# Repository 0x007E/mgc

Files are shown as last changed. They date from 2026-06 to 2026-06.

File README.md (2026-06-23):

  

# `MGC` - MeGARCard

The `MGC` is built as base development board with a set of push-buttons, leds, potentiometers and many more components on-board. It builds the base platform for a bunchset of adaptable microcontrolles (e.g. `ATmega16A`, `ATmega4808`, `ESP32`). It simplifies the development process by extending supported microcontrollers to a range of actuators and sensors. The board itself regulates the voltage to `5V` or `3V3` automatically with a power mux ([TPS2116](#additional-information)). If `3V3` and `5V` are suppored, the voltage can be changed on the dip switch of the adaptable microcontroller board. The base board supports a usb or uart-interface [FT230XS](#additional-information) to the adaptable microcontroller. The usb mode can be switched over a usb-multiplexer [TS3USB30](#additional-information) within the dip switch on the base board. The leds on the base bord are controlled over a transistor array [TBD62783](#additional-information) that keeps the input current on a very low state. 

> Note that the board should be disconnected from power sources when changing the state of the dip switches on the base or microcontroller adapter board.

| Experience  | Level |
|:---|:---:|
| Soldering | ?% |
| Mechanical  | ?% |

# Adapter-Boards

| ATmega16A | ATmega4809 | ESP32 |
|:---:|:---:|:-----:|
| Bottom Layer | Bottom Layer | Bottom Layer |
| Schematic | Schematic | Schematic |
| [pdf](https://github.com/0x007E/mgc_m16a/releases/latest/download/schematic.pdf) / [cadlab](https://cadlab.io/project/30414/main/files) | [pdf](https://github.com/0x007E/mgc_m4809/releases/latest/download/schematic.pdf) / [cadlab](https://cadlab.io/project/30419/main/files) | [pdf](https://github.com/0x007E/mgc_esp32/releases/latest/download/schematic.pdf) / [cadlab](https://cadlab.io/project/30425/main/files) |
| [GitHub](https://github.com/0x007e/mgc_m16a) | [GitHub](https://github.com/0x007e/mgc_m4809) | [GitHub](https://github.com/0x007e/mgc_esp32) |

# Downloads

| Type | File | Description |
|:---:|:---:|:---|
| Schematic | [pdf](https://github.com/0x007E/mgc/releases/latest/download/schematic.pdf) / [cadlab](https://cadlab.io/project/30413/main/files) | Schematic files |
| Board | [pdf](https://github.com/0x007E/mgc/releases/latest/download/pcb.pdf) / [cadlab](https://cadlab.io/project/30413/main/files) | Board file |
| Drill | [pdf](https://github.com/0x007E/mgc/releases/latest/download/drill.pdf) | Drill file |
| BoM | [xlsx](https://github.com/0x007E/mgc/releases/latest/download/bom.xlsx) / [html](https://github.com/0x007E/mgc/releases/latest/download/ibom.html) | Bill of Material as Excel/interactive HTML |
| PCB | [zip](https://github.com/0x007E/mgc/releases/latest/download/kicad.zip) / [tar](https://github.com/0x007E/mgc/releases/latest/download/kicad.tar.gz) | KiCAD/Gerber/BoM/Drill files |
| Mechanical | [zip](https://github.com/0x007E/mgc/releases/latest/download/freecad.zip) / [tar](https://github.com/0x007E/mgc/releases/latest/download/freecad.tar.gz) | FreeCAD/Housing and PCB (STEP/STL) files |

# Hardware

The pcb is created with `KiCAD`, the housing with `FreeCAD`. All files are built with `github actions` so that they are ready for a production environment.

## PCB

The circuit board is populated on both sides (Top, Bottom). The best way for soldering the `SMD` components is within a vapor phase soldering system and for the `THT` components with a standard soldering system.

### Top Layer

Top Layer

### Bottom Layer

Bottom Layer

## Mechanical

The housing has a tolerance of `0.2mm` on each side of the case. So the pcb should fit perfectly in the housing. The tolerance can be modified with `FreeCAD` in the `Parameter` Spreadsheet.

### Assembled

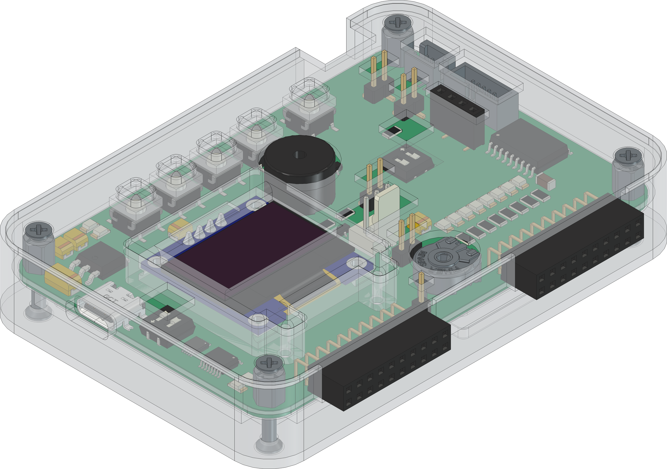
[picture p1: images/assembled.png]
Assembled


### Exploded

Exploded

# Additional Information

| Type | Link | Description |
|:---:|:---:|:---|
| FT230XS | [pdf](https://ftdichip.com/wp-content/uploads/2021/10/DS_FT230X.pdf) | USB/UART-Bridge |
| TS3USB30 | [pdf](https://www.ti.com/lit/ds/symlink/ts3usb30e.pdf) | USB-Multiplexer 1:2 |
| TPS2116 | [pdf](https://www.ti.com/lit/ds/symlink/tps2116.pdf) | Power Mux with Manual and Priority Switchover |
| TBD62783 | [pdf](https://toshiba.semicon-storage.com/info/datasheet_en_20160511.pdf) | DMOS transistor array |

---

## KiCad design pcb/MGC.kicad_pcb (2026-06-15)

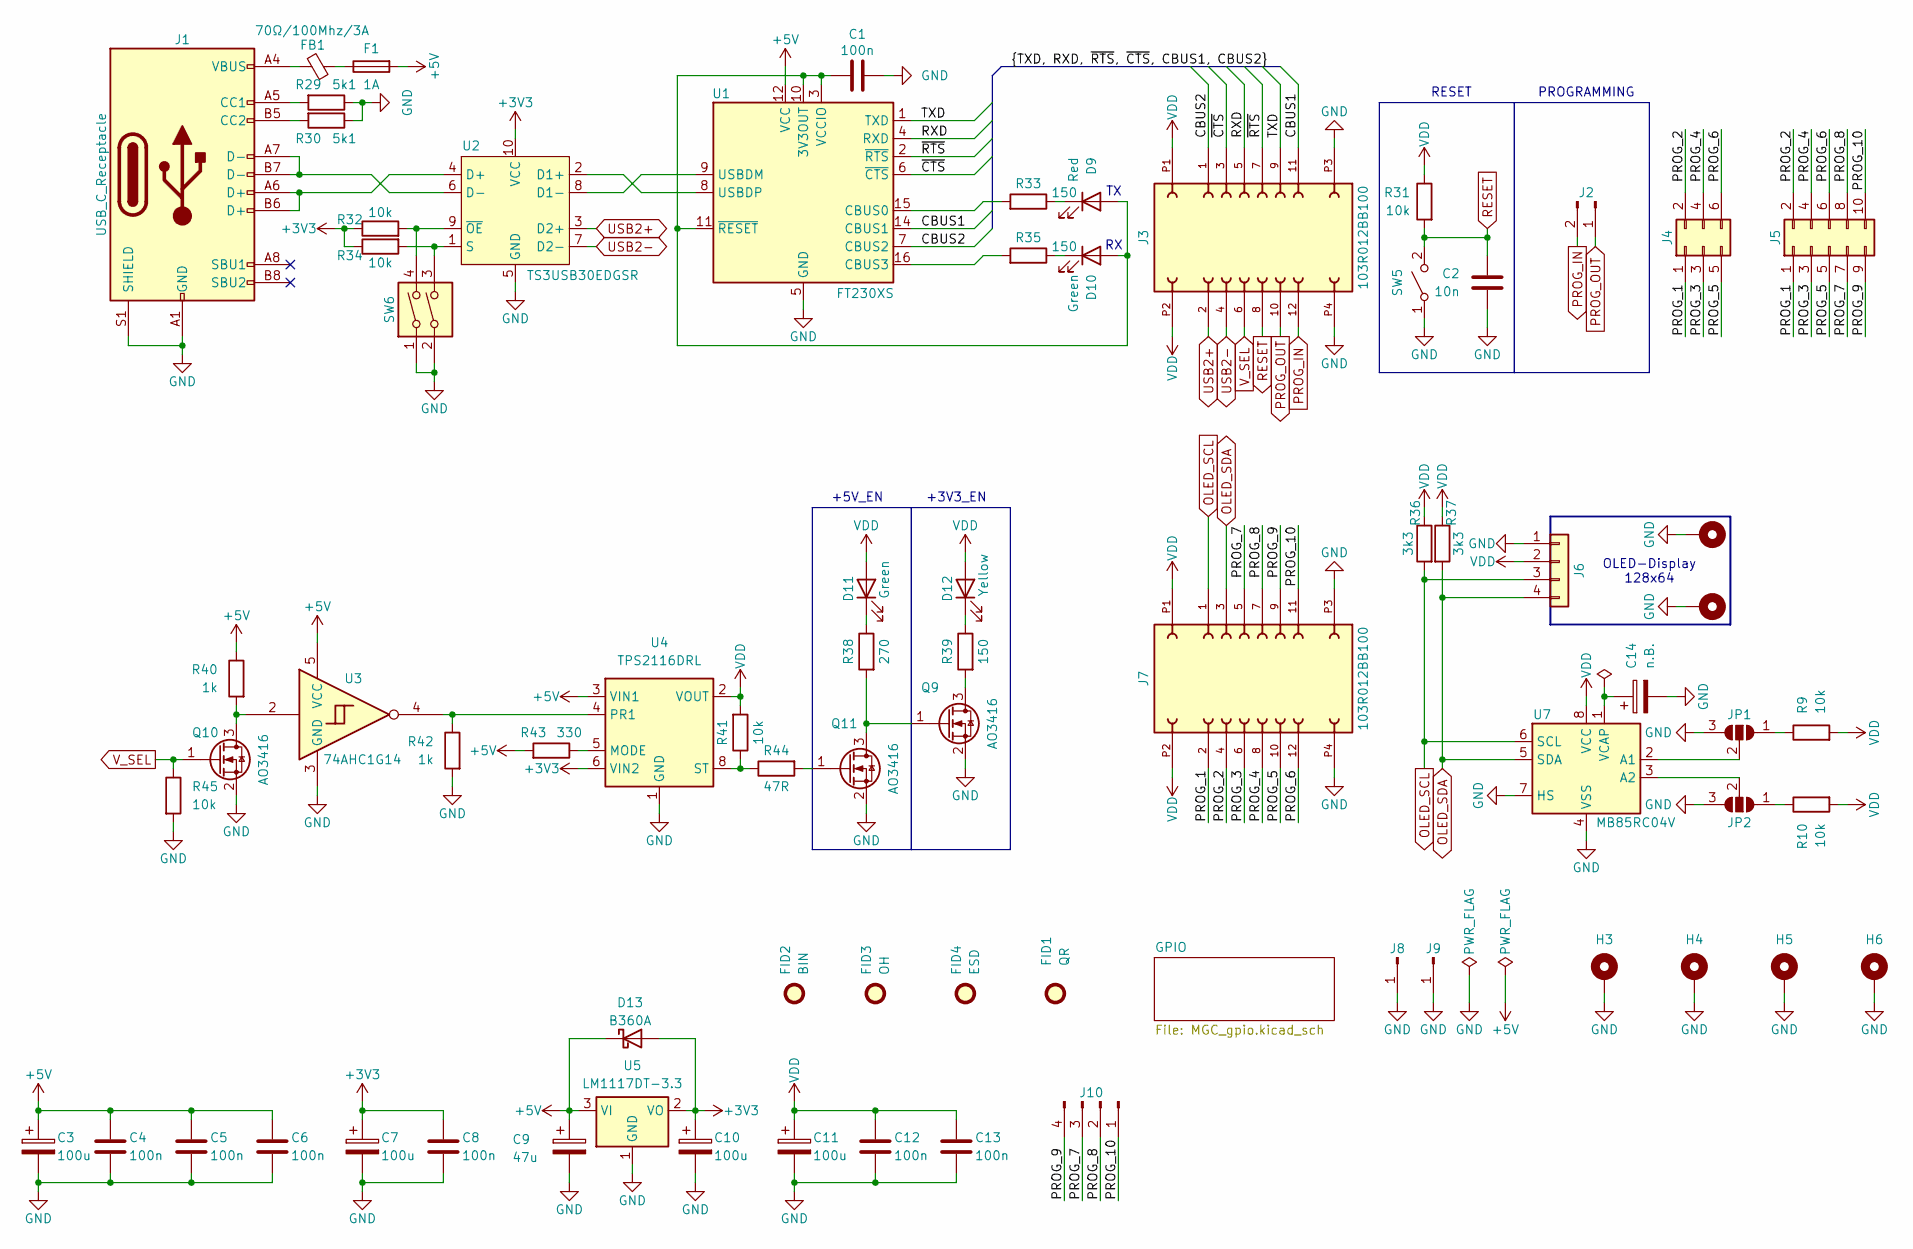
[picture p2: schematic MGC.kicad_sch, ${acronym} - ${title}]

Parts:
C1, C4, C5, C6, C8, C12, C13: 100n; C_1206_3216Metric
C2: 10n; C_0603_1608Metric
C3, C7, C10, C11: 100u; CP_EIA-3528-21_Kemet-B; DigiKey 478-3877-1-ND
C9: 47u; CP_EIA-6032-28_Kemet-C
C14: n.B.; CP_EIA-3528-21_Kemet-B
D9: Red; LED_1206_3216Metric
D10, D11: Green; LED_1206_3216Metric
D12: Yellow; LED_1206_3216Metric
D13: B360A; D_SMA
F1: 1A; Fuse_1206_3216Metric; DigiKey 5923-0ZCJ0100FF2ECT-ND
FB1: 70Ω/100Mhz/3A; L_1206_3216Metric
FID1: QR; QR_0x007e_very_small
FID2: BIN; WEEE-Logo_4.2x6mm_SilkScreen
FID3: OH; OSHW-Logo2_7.3x6mm_SilkScreen
FID4: ESD; ESD-Logo_6.6x6mm_SilkScreen
H1, H2, H3, H4, H5, H6: MountingHole_Pad; MountingHole_2.7mm_M2.5_DIN965_Pad
J1: USB_C_Receptacle; USB_C_Receptacle_GCT_USB4110
J2: Conn_01x02_Pin; PinHeader_1x02_P2.54mm_Vertical_SMD_Pin1Right; DigiKey HDR100IMP40M-G-V-SM-ND
J3, J7: 103R012BB100; AMPHENOL_103R012BB100; DigiKey 609-103R012BB100CT-ND
J4: Conn_02x03_Odd_Even; AMPHENOL_20021221-00006T4LF; DigiKey 609-20021221-00006T4LF-ND
J5: Conn_02x05_Odd_Even; AMPHENOL_20021521-00010T4LF; DigiKey 1175-1629-ND
J6: Conn_01x04; PinSocket_1x04_P2.54mm_Vertical
J8, J9: Conn_01x01_Pin; SolderWire-0.75sqmm_1x01_D1.25mm_OD3.5mm
J10: Conn_01x04_Pin; PinSocket_1x04_P2.54mm_Vertical_SMD_Pin1Right; DigiKey S5596-ND
JP1, JP2: SolderJumper_3_Open; SolderJumper-3_P1.3mm_Open_RoundedPad1.0x1.5mm_NumberLabels
Q9, Q10, Q11: AO3416; SOT-23
R9, R10, R31, R32, R34, R41, R45: 10k; R_1206_3216Metric
R29, R30: 5k1; R_1206_3216Metric
R33, R35, R39: 150; R_1206_3216Metric
R36, R37: 3k3; R_1206_3216Metric
R38: 270; R_1206_3216Metric
R40, R42: 1k; R_1206_3216Metric
R43: 330; R_1206_3216Metric
R44: 47R; R_1206_3216Metric
SW5: SW_SPST; SW_SPST_B3S-1000
SW6: SW_DIP_x02; SW_DIP_SPSTx02_Slide_6.7x6.64mm_W6.73mm_P2.54mm_LowProfile_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
U1: FT230XS; SSOP-16_3.9x4.9mm_P0.635mm
U2: TS3USB30EDGSR; VSSOP-10_3x3mm_P0.5mm; DigiKey 296-25495-1-ND
U3: 74AHC1G14; SOT-23-5
U4: TPS2116DRL; SOT-583-8; DigiKey 296-TPS2116DRLRCT-ND
U5: LM1117DT-3.3; TO-252-3_TabPin2
U7: MB85RC04V; SOIC-8_3.9x4.9mm_P1.27mm; DigiKey 47C16-I/SN-ND, 865-MB85RC04VPNF-G-AMERE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

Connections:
+3V3: C7.1, C8.1, C10.1, D13.2 (A), R32.1, R34.1, U2.10 (VCC), U4.6 (VIN2), U5.2 (VO)
+5V: C3.1, C4.1, C5.1, C6.1, C9.1, D13.1 (K), F1.2, R40.1, R43.2, U1.12 (VCC), U3.5 (VCC), U4.3 (VIN1), U5.3 (VI); also elsewhere on the board
/CBUS1: J3.11, U1.14 (CBUS1)
/CBUS2: J3.1, U1.7 (CBUS2)
/PROG_1: J4.1, J5.1, J7.2
/PROG_2: J4.2, J5.2, J7.4
/PROG_3: J4.3, J5.3, J7.6
/PROG_4: J4.4, J5.4, J7.8
/PROG_5: J4.5, J5.5, J7.10
/PROG_6: J4.6, J5.6, J7.12
/PROG_7: J5.7, J7.5, J10.3
/PROG_8: J5.8, J7.7, J10.2
/PROG_9: J5.9, J7.9, J10.4
/PROG_10: J5.10, J7.11, J10.1
/RXD: J3.5, U1.4 (RXD)
/TXD: J3.9, U1.1 (TXD)
/~CTS: J3.3, U1.6 (~CTS)
/~RTS: J3.7, U1.2 (~RTS)
GND: C1.2, C2.2, C3.2, C4.2, C5.2, C6.2, C7.2, C8.2, C9.2, C10.2, C11.2, C12.2, C13.2, C14.2, H1.1, H2.1, H3.1, H4.1, H5.1, H6.1, J1.A1 (GND), J1.A12 (GND), J1.B1 (GND), J1.B12 (GND), J1.S1 (SHIELD), J3.P3, J3.P4, J6.1, J7.P3, J7.P4, J8.1, J9.1, JP1.3 (B), JP2.3 (B), Q9.2 (S), Q10.2 (S), Q11.2 (S), R29.1, R30.1, R42.2, R45.2, SW5.1 (A), SW6.1, SW6.2, U1.5 (GND), U1.13 (GND), U2.5 (GND), U3.3 (GND), U4.1 (GND), U5.1 (GND), U7.4 (VSS), U7.7 (HS); also elsewhere on the board
unnamed: D9.1 (K), R33.1
unnamed: C1.1, D9.2 (A), D10.2 (A), U1.3 (VCCIO), U1.10 (3V3OUT), U1.11 (~RESET)
unnamed: D10.1 (K), R35.1
unnamed: D11.1 (K), R38.1
unnamed: D12.1 (K), R39.1
unnamed: F1.1, FB1.1
unnamed: FB1.2, J1.A4 (VBUS), J1.A9 (VBUS), J1.B4 (VBUS), J1.B9 (VBUS)
unnamed: J1.A5 (CC1), R29.2
unnamed: J1.B5 (CC2), R30.2
unnamed: JP1.1 (A), R9.1
unnamed: JP1.2 (C), U7.2 (A1)
unnamed: JP2.1 (A), R10.1
unnamed: JP2.2 (C), U7.3 (A2)
unnamed: Q9.3 (D), R39.2
unnamed: Q10.3 (D), R40.2, U3.2
unnamed: Q9.1 (G), Q11.3 (D), R38.2
unnamed: Q11.1 (G), R44.2
unnamed: R33.2, U1.15 (CBUS0)
unnamed: R35.2, U1.16 (CBUS3)
unnamed: U1.9 (USBDM), U2.8 (D1-)
unnamed: U1.8 (USBDP), U2.2 (D1+)
unnamed: J1.A6 (D+), J1.B6 (D+), U2.4 (D+)
unnamed: J1.A7 (D-), J1.B7 (D-), U2.6 (D-)
unnamed: R34.2, SW6.3, U2.1 (S)
unnamed: R32.2, SW6.4, U2.9 (~OE)
unnamed: R43.1, U4.5 (MODE)
unnamed: R42.1, U3.4, U4.4 (PR1)
unnamed: R41.1, R44.1, U4.8 (ST)
unnamed: C14.1, U7.1 (VCAP)
OLED_SCL: J6.3, J7.1, R36.2, U7.6 (SCL)
OLED_SDA: J6.4, J7.3, R37.2, U7.5 (SDA)
PROG_IN: J2.2, J3.12
PROG_OUT: J2.1, J3.10
RESET: C2.1, J3.8, R31.2, SW5.2 (B)
USB2+: J3.2, U2.3 (D2+)
USB2-: J3.4, U2.7 (D2-)
VDD: C11.1, C12.1, C13.1, D11.2 (A), D12.2 (A), J3.P1, J3.P2, J6.2, J7.P1, J7.P2, R9.2, R10.2, R31.1, R36.1, R37.1, R41.2, U4.2 (VOUT), U4.7 (VOUT), U7.8 (VCC); also elsewhere on the board
V_SEL: J3.6, Q10.1 (G), R45.1

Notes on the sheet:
PROGRAMMING
+3V3_EN
OLED-Display 128x64
RESET
+5V_EN

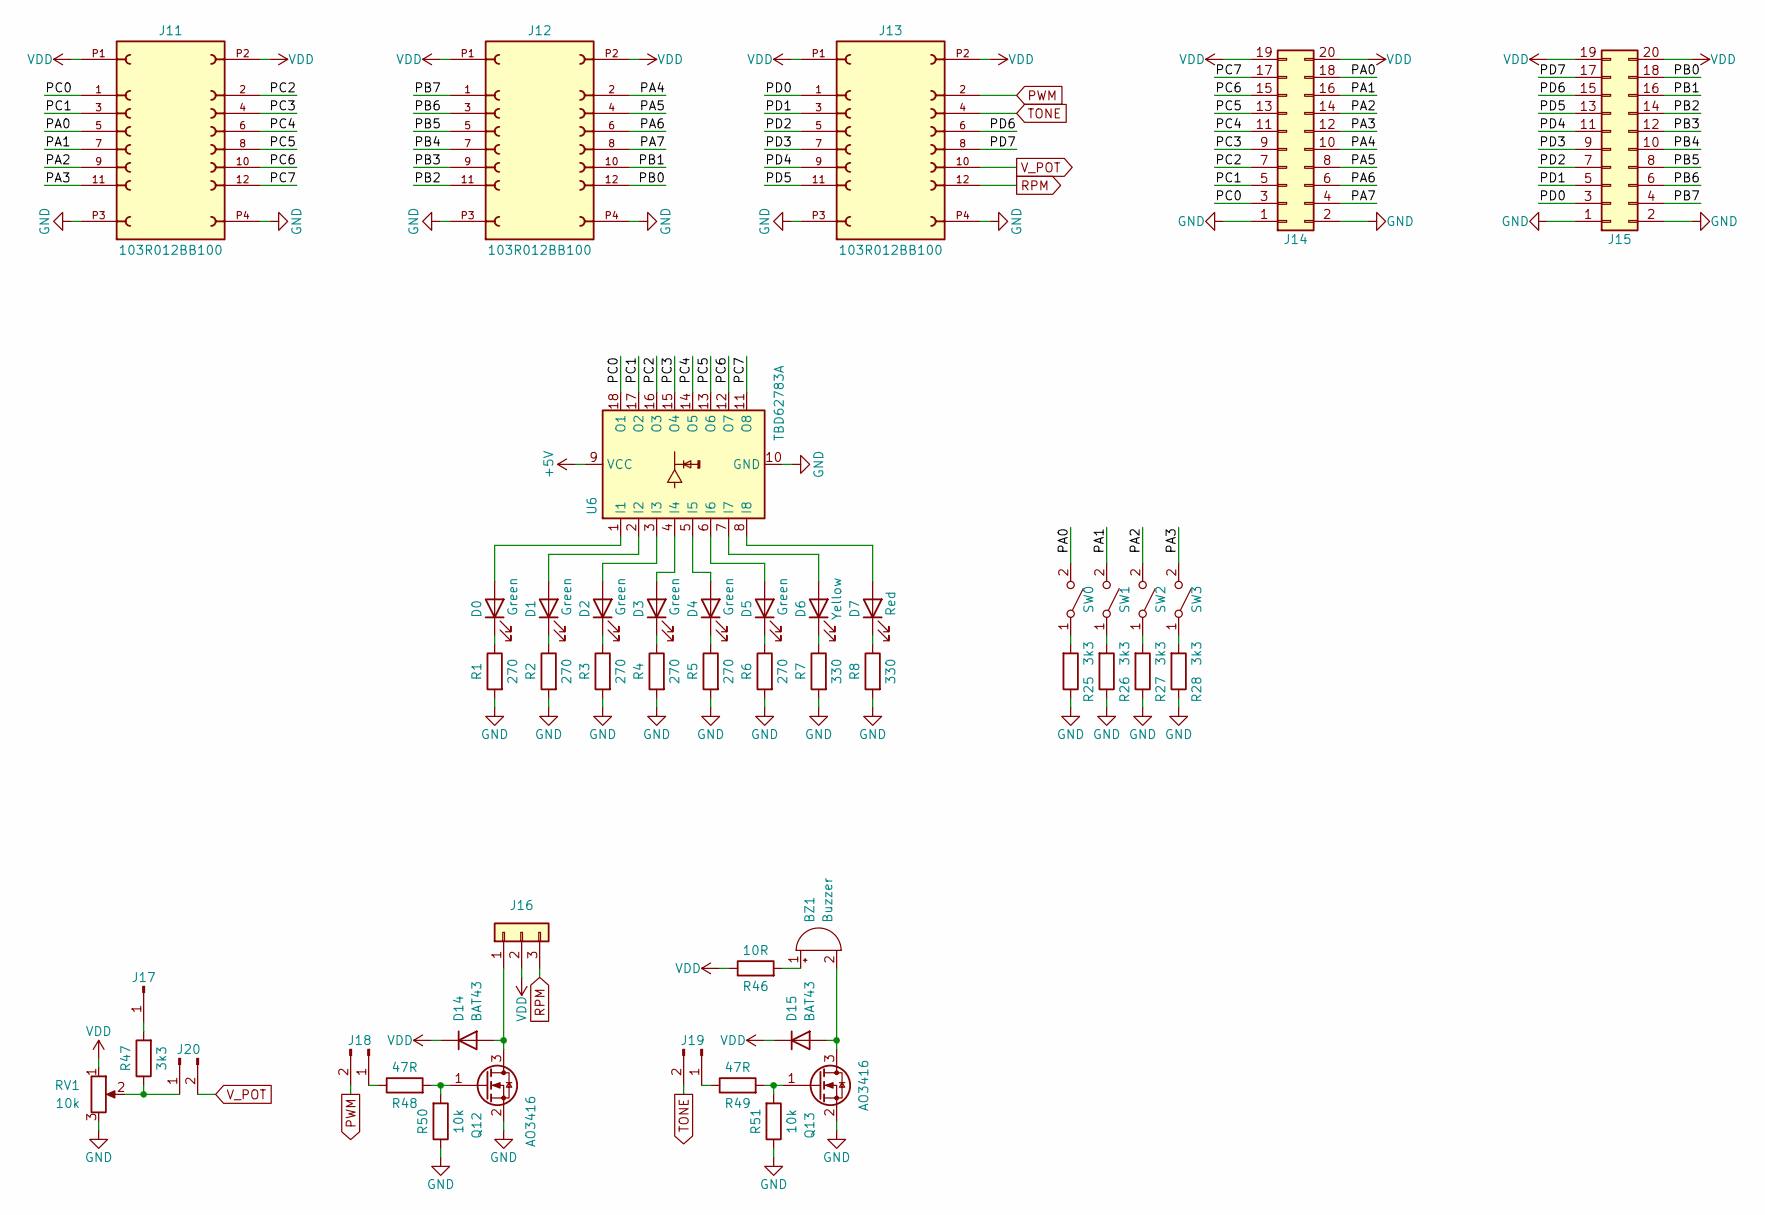
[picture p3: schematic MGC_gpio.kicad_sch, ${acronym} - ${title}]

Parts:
BZ1: Buzzer; MagneticBuzzer_ProSignal_ABT-410-RC
D0, D1, D2, D3, D4, D5: Green; LED_1206_3216Metric
D6: Yellow; LED_1206_3216Metric
D7: Red; LED_1206_3216Metric
D14, D15: BAT43; D_MiniMELF
J11, J12, J13: 103R012BB100; AMPHENOL_103R012BB100; DigiKey 609-103R012BB100CT-ND
J14, J15: Conn_02x10_Odd_Even; PinSocket_2x10_P2.54mm_Horizontal
J16: Conn_01x03; Molex_KK-254_AE-6410-03A_1x03_P2.54mm_Vertical; DigiKey WM4201-ND
J17: Conn_01x01_Pin; PinHeader_1x01_P2.54mm_Vertical
J18, J19, J20: Conn_01x02_Pin; PinHeader_1x02_P2.54mm_Vertical_SMD_Pin1Right; DigiKey HDR100IMP40M-G-V-SM-ND
Q12, Q13: AO3416; SOT-23
R1, R2, R3, R4, R5, R6: 270; R_1206_3216Metric
R7, R8: 330; R_1206_3216Metric
R25, R26, R27, R28, R47: 3k3; R_1206_3216Metric
R46: 10R; R_1206_3216Metric
R48, R49: 47R; R_1206_3216Metric
R50, R51: 10k; R_1206_3216Metric
RV1: 10k; Potentiometer_Piher_PT-10-V10_Vertical
SW0, SW1, SW2, SW3: SW_SPST; SW_SPST_B3S-1000
U6: TBD62783A; SOIC-18W_7.5x11.6mm_P1.27mm; DigiKey TBD62783AFGELCT-ND

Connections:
+5V: U6.9 (VCC); also elsewhere on the board
/GPIO/PA0: J11.5, J14.18, SW0.2 (B)
/GPIO/PA1: J11.7, J14.16, SW1.2 (B)
/GPIO/PA2: J11.9, J14.14, SW2.2 (B)
/GPIO/PA3: J11.11, J14.12, SW3.2 (B)
/GPIO/PA4: J12.2, J14.10
/GPIO/PA5: J12.4, J14.8
/GPIO/PA6: J12.6, J14.6
/GPIO/PA7: J12.8, J14.4
/GPIO/PB0: J12.12, J15.18
/GPIO/PB1: J12.10, J15.16
/GPIO/PB2: J12.11, J15.14
/GPIO/PB3: J12.9, J15.12
/GPIO/PB4: J12.7, J15.10
/GPIO/PB5: J12.5, J15.8
/GPIO/PB6: J12.3, J15.6
/GPIO/PB7: J12.1, J15.4
/GPIO/PC0: J11.1, J14.3, U6.18 (O1)
/GPIO/PC1: J11.3, J14.5, U6.17 (O2)
/GPIO/PC2: J11.2, J14.7, U6.16 (O3)
/GPIO/PC3: J11.4, J14.9, U6.15 (O4)
/GPIO/PC4: J11.6, J14.11, U6.14 (O5)
/GPIO/PC5: J11.8, J14.13, U6.13 (O6)
/GPIO/PC6: J11.10, J14.15, U6.12 (O7)
/GPIO/PC7: J11.12, J14.17, U6.11 (O8)
/GPIO/PD0: J13.1, J15.3
/GPIO/PD1: J13.3, J15.5
/GPIO/PD2: J13.5, J15.7
/GPIO/PD3: J13.7, J15.9
/GPIO/PD4: J13.9, J15.11
/GPIO/PD5: J13.11, J15.13
/GPIO/PD6: J13.6, J15.15
/GPIO/PD7: J13.8, J15.17
GND: J11.P3, J11.P4, J12.P3, J12.P4, J13.P3, J13.P4, J14.1, J14.2, J15.1, J15.2, Q12.2 (S), Q13.2 (S), R1.2, R2.2, R3.2, R4.2, R5.2, R6.2, R7.2, R8.2, R25.1, R26.1, R27.1, R28.1, R50.1, R51.1, RV1.3, U6.10 (GND); also elsewhere on the board
unnamed: BZ1.1 (+), R46.2
unnamed: BZ1.2 (-), D15.2 (A), Q13.3 (D)
unnamed: D0.2 (A), U6.1 (I1)
unnamed: D0.1 (K), R1.1
unnamed: D1.2 (A), U6.2 (I2)
unnamed: D1.1 (K), R2.1
unnamed: D2.2 (A), U6.3 (I3)
unnamed: D2.1 (K), R3.1
unnamed: D3.2 (A), U6.4 (I4)
unnamed: D3.1 (K), R4.1
unnamed: D4.2 (A), U6.5 (I5)
unnamed: D4.1 (K), R5.1
unnamed: D5.2 (A), U6.6 (I6)
unnamed: D5.1 (K), R6.1
unnamed: D6.2 (A), U6.7 (I7)
unnamed: D6.1 (K), R7.1
unnamed: D7.2 (A), U6.8 (I8)
unnamed: D7.1 (K), R8.1
unnamed: D14.2 (A), J16.1, Q12.3 (D)
unnamed: J17.1, R47.2
unnamed: J18.1, R48.1
unnamed: J19.1, R49.1
unnamed: J20.1, R47.1, RV1.2
unnamed: Q12.1 (G), R48.2, R50.2
unnamed: Q13.1 (G), R49.2, R51.2
unnamed: R25.2, SW0.1 (A)
unnamed: R26.2, SW1.1 (A)
unnamed: R27.2, SW2.1 (A)
unnamed: R28.2, SW3.1 (A)
PWM: J13.2, J18.2
RPM: J13.12, J16.3
TONE: J13.4, J19.2
VDD: D14.1 (K), D15.1 (K), J11.P1, J11.P2, J12.P1, J12.P2, J13.P1, J13.P2, J14.19, J14.20, J15.19, J15.20, J16.2, R46.1, RV1.1; also elsewhere on the board
V_POT: J13.10, J20.2

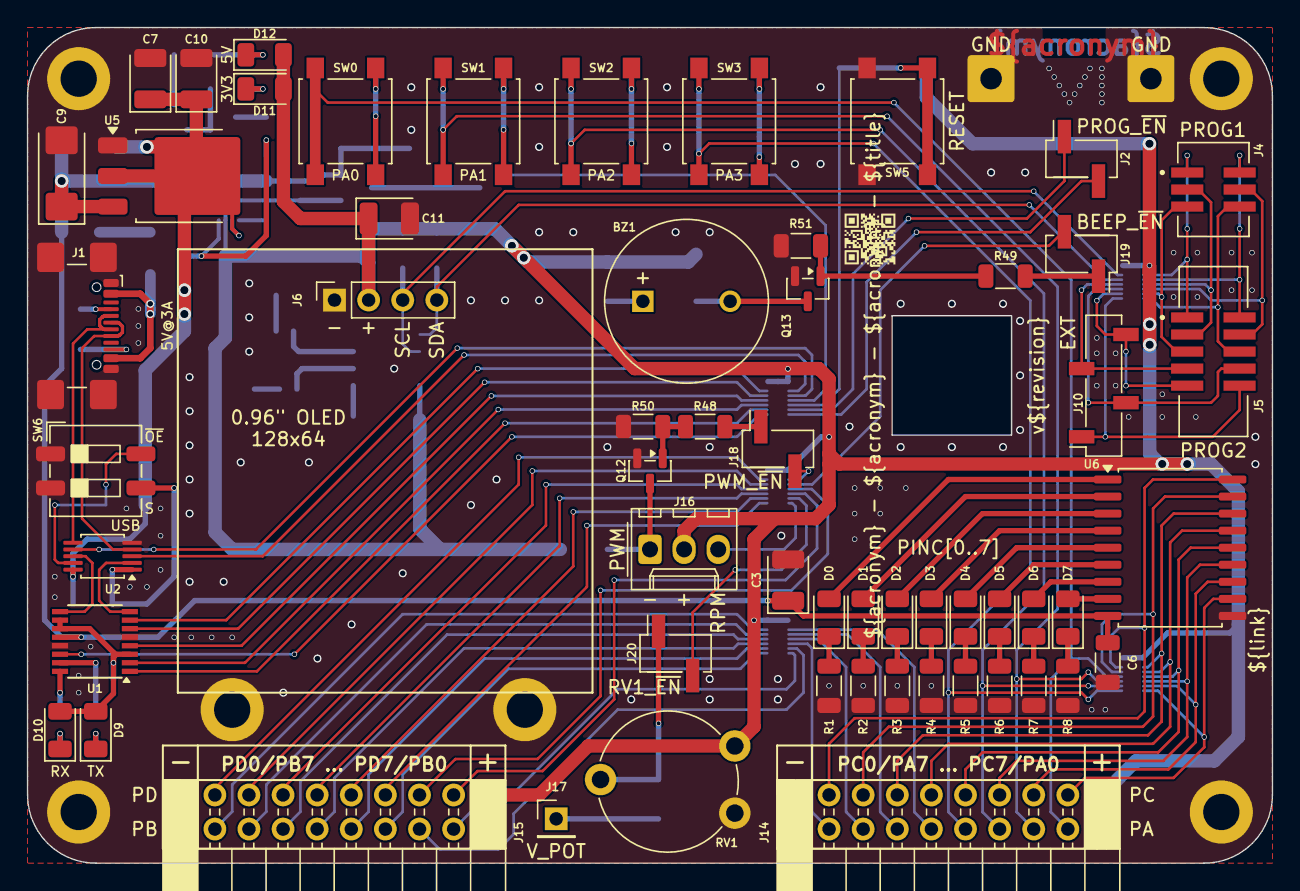
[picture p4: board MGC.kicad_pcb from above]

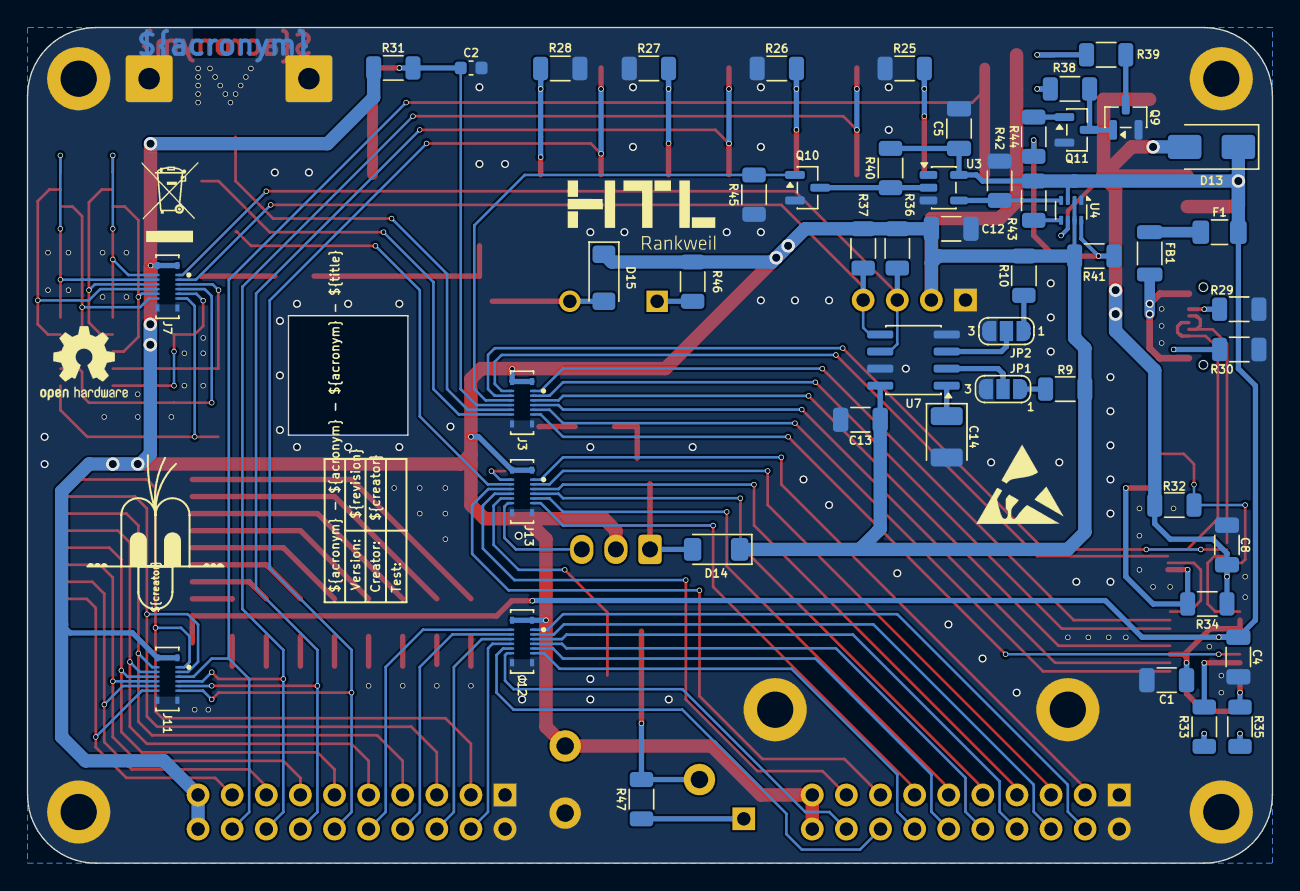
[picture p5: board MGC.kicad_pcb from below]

Board: 2 copper layers, 92.7 x 62.2 mm, 120 parts (54 on the bottom side), 122 nets.

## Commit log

2026-06-08 Add pcb layout
    [MGC.kicad_pcb, MGC.kicad_sch, MGC_gpio.kicad_sch]
2026-06-09 Optimize fabrication layer
    [MGC.kicad_pcb]
2026-06-09 Adapt device values
    [MGC.kicad_pcb, MGC.kicad_sch, MGC_gpio.kicad_sch]
2026-06-09 Add missing vendor(id)
    [MGC.kicad_pcb, MGC.kicad_sch, MGC_gpio.kicad_sch]
2026-06-09 Fix connector pin direction
    [MGC.kicad_pcb, MGC.kicad_sch, MGC_gpio.kicad_sch]
2026-06-09 Add dimensioning
    [MGC.kicad_pcb]
2026-06-09 Fix wrong acronym
    [MGC.kicad_pcb]
2026-06-09 Fix wrong label direction
    [MGC_gpio.kicad_sch]
2026-06-11 Change reset capacitor device size
    [MGC.kicad_pcb, MGC.kicad_sch]
2026-06-13 Device repositioning
    [MGC.kicad_pcb]
2026-06-13 Move display mounting hole
    [MGC.kicad_pcb]
2026-06-15 Fix wrong connector dimension
    [MGC.kicad_pcb]
2026-06-15 Add missing dimensions
    [MGC.kicad_pcb]
2026-06-15 Adapt display position
    [MGC.kicad_pcb]
2026-06-15 Add assembly explosion
2026-06-17 Change adapter board images to thumbnails
2026-06-23 Add missing values in bom
2026-06-23 Add manufactor to bom

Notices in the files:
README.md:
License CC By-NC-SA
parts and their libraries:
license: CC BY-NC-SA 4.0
